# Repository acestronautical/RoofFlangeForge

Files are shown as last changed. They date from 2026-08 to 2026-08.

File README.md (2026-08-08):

# Roof Flange Forge

Design and 3D-print flange adapters that mount cleanly on a ribbed sheet-metal
roof — van roofs, shed roofs, RV panels, corrugated agricultural buildings.
Enter your roof's rib profile, pick a flange shape, and download an STL that
bridges the ribs and gives a fan, vent, skylight, or duct a flat, sealable
base.

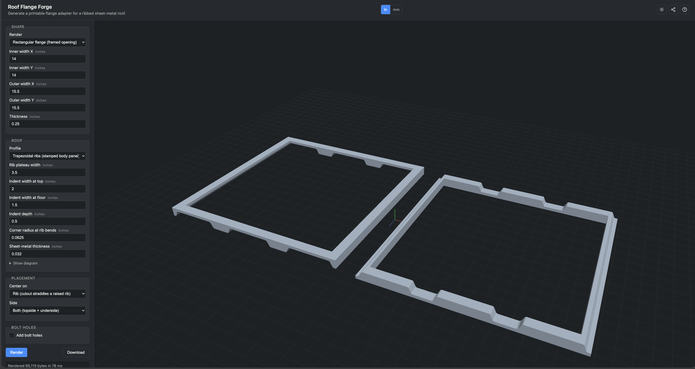
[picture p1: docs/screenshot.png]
Roof Flange Forge


## Get it

- **In your browser** — <https://acestronautical.github.io/RoofFlangeForge/>
- **As a desktop app** — [download the latest release](https://github.com/acestronautical/RoofFlangeForge/releases/latest)
  for macOS, Windows, or Linux

Both versions do the same thing and work fully offline once loaded.

## What you can make

- **Circular flange** — round mounting ring for round-flange fittings (Maxxair
  Dome, 6"–7" vents, roof jacks, small skylights)
- **Rectangular flange** — framed opening for fans in a rectangular cutout
  (defaults suit MaxxFan-family 14×14" fans)
- **Strip** — a mounting bar with no cutout, for roof-rack rails, panel mount
  bases, cable tie-downs
- **Roof preview** — an at-a-glance cross-section of the profile you configured,
  handy when you're eyeballing whether your numbers match the real panel

Every flange can be configured for either a **trapezoidal** roof (stamped body
panels, most vans) or a **corrugated** roof (sinusoidal, e.g. barn tin), and
comes in a **topside** piece, an **underside** piece, or **both at once** (both
mating parts spread apart in one STL, ready to sandwich the sheet metal
between them).

Optional bolt holes can be turned on with a single click. They auto-center on
the ring material and expose a signed offset to nudge them inward or outward.

## Using it

1. Open the app, pick **inches** or **millimeters** at the top.
2. Pick a **Shape** and set its size.
3. Set the **Roof** profile and dimensions to match the sheet metal you're
   mounting on. Every field has a hover hint; the **Show diagram** link at
   the bottom of the Roof section pops up a labeled cross-section.
4. Choose **Placement** — whether the flange center sits over a rib or an
   indent, and whether you're printing the topside, underside, or both.
5. Turn on **Bolt holes** if you want the holes pre-drilled.
6. Hit **Render**, review the preview, then **Download**.

The share button in the top-right copies a link that reproduces your exact
STL — bookmark it, send it to a friend, or come back to it later.

Read the [help modal](https://acestronautical.github.io/RoofFlangeForge/?help=1)
in the app for tips on tolerance adjustments (loose fit, snug fit, sheet
thickness, corner radius) before you commit to a full print.

## Credits

Development notes for the code are in [DEV.md](DEV.md).

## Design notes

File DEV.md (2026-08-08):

# Developer notes

Public docs live in [README.md](README.md). This file is for people working
on the code.

## Layout

```
cli/scad/                  Parametric SCAD sources (single source of truth)
cli/build_stls.sh          Batch-render every variant into generated_stl/
cli/tests/reproducibility.sh   Two-render byte-diff test (7 configs)
web/                       Vite + TypeScript + three.js web app
web/electron/main.cjs      Electron main process (npm run electron:dist)
web/public/openscad/       Vendored openscad-wasm (Manifold, ~11 MB)
web/public/scad -> ../../cli/scad   symlink; single source of truth for SCAD
.github/workflows/
  pages.yml                Push to main -> deploy web app to GitHub Pages
  test.yml                 Push / PR -> reproducibility test (nightly OpenSCAD)
  release.yml              Tag push (v*) -> build .dmg/.exe/.AppImage matrix
  build-openscad-wasm.yml  Manual dispatch -> rebuild openscad-wasm, open PR
```

## Local dev

```bash
cd web
npm install
npm run dev        # http://localhost:5173
npm run typecheck
npm run electron:dev   # runs Electron pointed at the Vite server
npm run electron:dist  # packages a signed installer for your host OS
```

## CLI

Install a modern OpenSCAD locally (`brew install openscad`), then one-off:

```bash
openscad \
    -D 'ID=6.375' \
    -D 'OD=10.5' \
    -D 'side="top"' \
    -D 'bolt_holes=true' \
    -o adapter.stl \
    cli/scad/circular_adapter.scad
```

Every top-level variable in the SCAD is overridable via `-D`.

`cli/build_stls.sh` batch-renders the standard variants.

## Reproducibility test

`cli/tests/reproducibility.sh` renders a 7-config matrix twice with the same
OpenSCAD binary and asserts byte-identical output. Catches accidental
non-determinism (unset variables, iteration-order sensitivity, floating-point
edge cases) that would break shareable-URL reproducibility.

Run locally: `bash cli/tests/reproducibility.sh`. On CI the workflow installs
the nightly OpenSCAD AppImage — Ubuntu's apt is too old for Manifold (which
is deterministic; CGAL isn't for our bolt-hole configs).

## Cutting a release

```bash
git tag v0.2.0
git push --tags
```

The **Release desktop builds** workflow packages the Electron app on
macos-latest / windows-latest / ubuntu-latest in parallel and attaches the
installers to the GitHub Release for that tag via `softprops/action-gh-release`.

If you need to redo a release: `git push origin :v0.2.0 && git tag -d v0.2.0 &&
git tag v0.2.0 && git push --tags` (force re-tag, retriggers the workflow).

## Upgrading openscad-wasm

Actions tab → **Build openscad-wasm from main** → *Run workflow*. Docker-builds
openscad-wasm from source, filters out the fonts+MCAD files we don't use,
copies the fresh artifacts into `web/public/openscad/`, and opens a PR to
review. Merge to ship.

If the workflow fails at "Open PR" with
*"GitHub Actions is not permitted to create or approve pull requests"*, either
open the PR manually from the pushed branch `chore/openscad-wasm-upgrade`, or
enable the setting at *Repo Settings → Actions → General → Workflow permissions*.

## Design notes

- The roof profile is periodic: **trapezoidal** is defined by `rib_width`,
  `indent_top_w`, `indent_bot_w`, `indent_depth`, `corner_r`; **corrugated**
  by `corr_pitch` and `corr_depth`.
- Chamfered rib bends are baked into the surface polygon (no offset/minkowski
  gymnastics), so the geometry stays manifold at any `corner_r`. See
  `chamfer_polyline` in `trapezoidal_roof.scad`.
- Every adapter is `blank − roof_cutter − bolt_pattern` (bolts opt-in).
  Topside and underside are the two halves of one prism split along the
  roof surface, with a `sheet_thickness` gap between them. Their union fills
  a constant-thickness volume.
- `roof_cutter()` dispatches on `roof_profile` at render time, so switching
  between trapezoidal and corrugated is one variable, not a different file.
- Top-level `render_all()` handles `side="both"` by translating a topside
  and an underside apart and rendering both — makes a print-ready STL with
  both mating parts on the bed in one job.
- `bolt_pattern.scad` is fully isolated: adapters `include` it and gate its
  effect on a `bolt_holes = false` default. Set the flag off and the STL is
  byte-identical to a build without the file.

## Deploying

The `Deploy to GitHub Pages` workflow triggers on every push to `main`. It
builds the web app with `base: "/RoofFlangeForge/"` and publishes
`web/dist/` to Pages. The Electron build uses the same source with a relative
base URL (`ELECTRON=1 vite build`).

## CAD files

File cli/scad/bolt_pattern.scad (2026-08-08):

// =============================================================================
// bolt_pattern.scad
//
// Bolt-hole cutter modules. Each generates a set of vertical through-hole
// cylinders you subtract from an adapter body. Fully self-contained: no
// dependency on adapter geometry beyond the enable flag and pass-through
// dimensions.
//
// Every adapter honors a top-level `bolt_holes = false` variable; when set
// true, the adapter subtracts the matching bolt pattern in a difference()
// pass. Leave the flag off (the default) and this file has zero effect --
// the geometry is byte-identical to the pre-bolt-holes version.
// =============================================================================

bolt_eps = 0.010;                        // face-clearing overlap on each end

// Centered vertically around z=0; caller sizes h to span the adapter.
module bolt_cyl(d, h) {
    translate([0, 0, -h/2])
        cylinder(h = h, d = d, $fn = 32);
}

// n bolts evenly spaced on a bolt circle of diameter pcd.
module circular_bolt_pattern(n, pcd, hole_d, h, angle_offset = 0) {
    for (i = [0 : n-1]) {
        a = angle_offset + i * 360 / n;
        translate([pcd/2 * cos(a), pcd/2 * sin(a), 0])
            bolt_cyl(hole_d, h);
    }
}

// Bolts around the perimeter of a rectangle: corners are always included,
// with n_per_side controlling total bolts on each edge (corners shared
// between the two edges they touch, so n_per_side = 2 gives 4 total,
// n_per_side = 3 gives 8, n_per_side = 4 gives 12, etc.).
module rectangular_bolt_pattern(outer_x, outer_y, n_per_side, edge_inset, hole_d, h) {
    ex = outer_x / 2 - edge_inset;
    ey = outer_y / 2 - edge_inset;

    for (p = [[+ex, +ey], [-ex, +ey], [+ex, -ey], [-ex, -ey]])
        translate([p[0], p[1], 0]) bolt_cyl(hole_d, h);

    if (n_per_side >= 3) {
        for (i = [1 : n_per_side - 2]) {
            x = -ex + i * (2 * ex) / (n_per_side - 1);
            y = -ey + i * (2 * ey) / (n_per_side - 1);
            translate([x, +ey, 0]) bolt_cyl(hole_d, h);
            translate([x, -ey, 0]) bolt_cyl(hole_d, h);
            translate([+ex, y, 0]) bolt_cyl(hole_d, h);
            translate([-ex, y, 0]) bolt_cyl(hole_d, h);
        }
    }
}

// n evenly-spaced bolts on the centerline of a strip of length strip_x.
module strip_bolt_pattern(strip_x, n, edge_inset, hole_d, h) {
    xs = n == 1 ? [0]
        : [ for (i = [0 : n-1]) -strip_x/2 + edge_inset + i * (strip_x - 2*edge_inset) / (n - 1) ];
    for (x = xs)
        translate([x, 0, 0]) bolt_cyl(hole_d, h);
}

// Drop a bolt at each X in xs, on the strip centerline (y=0).
module bolt_column_at(xs, hole_d, h) {
    for (x = xs)
        translate([x, 0, 0]) bolt_cyl(hole_d, h);
}

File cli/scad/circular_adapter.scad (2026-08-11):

// =============================================================================
// circular_adapter.scad
//
// An annular mounting adapter that conforms to a periodic trapezoidal-rib
// roof (see trapezoidal_roof.scad).
//
// The topside and underside variants are the two halves of a single cylinder
// split along the roof surface:
//
//   side = "top"    -> the piece ABOVE the roof, with pads that drop DOWN
//                      into the indents
//   side = "bottom" -> the piece BELOW the roof, with pockets that receive
//                      those pads from below
//
// Their union fills a solid ring cylinder of thickness `main_thick + indent_depth`
// on each side of the roof plateau plane (2 * main_thick when main_thick equals
// indent_depth, which is the default).
//
// All dimensions in inches; final scale converts to millimeters.
// =============================================================================

include <trapezoidal_roof.scad>
include <corrugated_roof.scad>
include <bolt_pattern.scad>

// -----------------------------------------------------------------------------
// Roof profile: which cross-section to conform the underside to
// -----------------------------------------------------------------------------
roof_profile = "trapezoidal";            // "trapezoidal" or "corrugated"
roof_depth   = (roof_profile == "corrugated") ? corr_depth : indent_depth;

// -----------------------------------------------------------------------------
// Adapter shape
// -----------------------------------------------------------------------------
ID          = 6.500;                      // inner diameter (must be >= the opening you're framing)
OD          = 10.000;                     // outer diameter
main_thick  = roof_depth;                 // thickness of this piece above (topside) or below (underside) the rib plateau plane

// -----------------------------------------------------------------------------
// Position of the flange center on the roof and which side the adapter mounts on
// -----------------------------------------------------------------------------
flange_offset_x = 0;                         // 0 = rib-centered; indent_center_x = indent-centered
side         = "top";                     // "top" (outside), "bottom" (inside), or "both" (both sides side by side)

// -----------------------------------------------------------------------------
// Fit tolerance: uniform clearance normal to the roof surface. Grows the
// cutter (via offset() before extrusion) so the printed pads sit in the
// real indents with slop instead of an exact-fit wedge. The plateau contact
// line is preserved via an intersection clip -- see trapezoidal_roof.scad.
// -----------------------------------------------------------------------------
tolerance   = 0;                          // per-side clearance around the roof-mating features

// -----------------------------------------------------------------------------
// Bolt holes (opt-in). See bolt_pattern.scad.
// -----------------------------------------------------------------------------
bolt_holes  = false;                      // set true to subtract a bolt pattern
bolt_n      = 8;                          // number of bolts on the bolt circle
bolt_pcd    = (ID + OD) / 2;              // pitch circle diameter (default: centered on the ring)
bolt_angle  = 0;                          // rotation of the bolt pattern about the flange center, in degrees
bolt_hole_d = 0.250;                      // through-hole diameter

// -----------------------------------------------------------------------------
// Render controls
// -----------------------------------------------------------------------------
$fn    = 240;
IN2MM  = 25.4;

// -----------------------------------------------------------------------------
// Derived: cutter extents. Z range is computed per-side inside the module
// (see circular_adapter) so "both" mode can render top + bottom at once.
// -----------------------------------------------------------------------------
cut_xy = 2 * OD;
cut_z  = 4 * roof_depth;

scale([IN2MM, IN2MM, IN2MM]) render_all();

// =============================================================================
// Modules
// =============================================================================

module render_all() {
    if (side == "both") {
        gap = OD * 1.1;
        translate([-gap/2, 0, 0]) circular_adapter("top");
        translate([+gap/2, 0, 0]) circular_adapter("bottom");
    } else {
        circular_adapter(side);
    }
}

module circular_adapter(s = side) {
    z_top = (s == "top") ? +main_thick    : -sheet_thickness;
    z_bot = (s == "top") ? -roof_depth    : -main_thick - roof_depth - sheet_thickness;
    difference() {
        translate([0, 0, z_bot])
            linear_extrude(height = z_top - z_bot)
                difference() {
                    circle(d = OD);
                    circle(d = ID);
                }
        roof_cutter(s);
        if (bolt_holes)
            circular_bolt_pattern(
                n            = bolt_n,
                pcd          = bolt_pcd,
                hole_d       = bolt_hole_d,
                h            = 4 * (main_thick + roof_depth + sheet_thickness),
                angle_offset = bolt_angle
            );
    }
}

module roof_cutter(s = side) {
    if (roof_profile == "corrugated")
        corrugated_roof_cutter(
            flange_offset_x = flange_offset_x,
            pitch        = corr_pitch,
            depth        = corr_depth,
            cut_xy       = cut_xy,
            cut_z        = cut_z,
            side         = s,
            thickness    = sheet_thickness,
            tolerance    = tolerance
        );
    else
        trapezoidal_roof_cutter(
            flange_offset_x = flange_offset_x,
            cut_xy       = cut_xy,
            cut_z        = cut_z,
            side         = s,
            thickness    = sheet_thickness,
            tolerance    = tolerance
        );
}

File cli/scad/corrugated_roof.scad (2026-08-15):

// =============================================================================
// corrugated_roof.scad
//
// Parametric model of a periodic sinusoidal "corrugated" sheet-metal roof --
// the classic wavy metal panel seen on sheds, barns, and some industrial
// vehicles. Signature-compatible with trapezoidal_roof.scad's cutter so the
// adapters can dispatch between the two at render time.
//
// Exports:
//     module corrugated_roof_cutter(...)  - solid block on one side of the
//                                           roof surface, sized for
//                                           subtraction from a blank.
//     module corrugated_roof_sheet(...)   - thin sheet-metal-like
//                                           visualization of the roof.
//
// The trapezoidal file owns `sheet_thickness` (and `corner_r`); this file
// only declares corrugated-specific variables so both can be `include`d in
// the same adapter without collisions.
// =============================================================================

// -----------------------------------------------------------------------------
// Corrugated cross-section defaults (inches). Overridable via -D.
// -----------------------------------------------------------------------------
corr_pitch = 2.667;    // rib-to-rib spacing (one full wave, "wavelength")
corr_depth = 0.500;    // peak-to-trough vertical distance

// Derived
corr_indent_center_x = corr_pitch / 2;   // half-wavelength from a peak = trough centerline

// =============================================================================
// corrugated_roof_cutter(flange_offset_x, pitch, depth, cut_xy, cut_z, side,
//                       thickness, samples_per_pitch)
//
// See trapezoidal_roof_cutter for parameter semantics. `flange_offset_x = 0`
// puts a peak (rib) at X = 0; `flange_offset_x = corr_indent_center_x` puts a
// trough (indent) at X = 0.
// =============================================================================
module corrugated_roof_cutter(
    flange_offset_x      = 0,
    pitch             = corr_pitch,
    depth             = corr_depth,
    cut_xy            = 40,
    cut_z             = 5,
    side              = "top",
    thickness         = 0.032,
    samples_per_pitch = 64,
    tolerance         = 0
) {
    z_shift = (side == "bottom") ? -thickness : 0;
    // top_y is the tiny above-plateau overlap baked into the profile; used
    // here as the plateau reference line for the tolerance clip.
    top_y = 0.010;
    translate([0, 0, z_shift])
        rotate([90, 0, 0])
            linear_extrude(height = 2*cut_xy, center = true)
                if (tolerance <= 0) {
                    corrugated_roof_profile_2d(
                        flange_offset_x      = flange_offset_x,
                        pitch             = pitch,
                        depth             = depth,
                        cut_xy            = cut_xy,
                        cut_z             = cut_z,
                        side              = side,
                        samples_per_pitch = samples_per_pitch
                    );
                } else if (side == "top") {
                    intersection() {
                        offset(delta = tolerance)
                            corrugated_roof_profile_2d(
                                flange_offset_x      = flange_offset_x,
                                pitch             = pitch,
                                depth             = depth,
                                cut_xy            = cut_xy,
                                cut_z             = cut_z,
                                side              = "top",
                                samples_per_pitch = samples_per_pitch
                            );
                        translate([-2*cut_xy, -2*cut_z])
                            square([4*cut_xy, 2*cut_z + top_y]);
                    }
                } else {
                    // See trapezoidal_roof_cutter for the rationale: for the
                    // bottom side we can't just clip the offset polygon,
                    // because the trough pockets live below the plateau
                    // line and a symmetric clip would erase them. Union the
                    // above-plateau slice of the offset with an offset of
                    // just the below-plateau trough bulges instead.
                    union() {
                        intersection() {
                            offset(delta = tolerance)
                                corrugated_roof_profile_2d(
                                    flange_offset_x      = flange_offset_x,
                                    pitch             = pitch,
                                    depth             = depth,
                                    cut_xy            = cut_xy,
                                    cut_z             = cut_z,
                                    side              = "bottom",
                                    samples_per_pitch = samples_per_pitch
                                );
                            translate([-2*cut_xy, top_y])
                                square([4*cut_xy, 4*cut_z]);
                        }
                        offset(delta = tolerance) intersection() {
                            corrugated_roof_profile_2d(
                                flange_offset_x      = flange_offset_x,
                                pitch             = pitch,
                                depth             = depth,
                                cut_xy            = cut_xy,
                                cut_z             = cut_z,
                                side              = "bottom",
                                samples_per_pitch = samples_per_pitch
                            );
                            translate([-2*cut_xy, -2*cut_z])
                                square([4*cut_xy, 2*cut_z + top_y]);
                        }
                    }
                }
}

// The 2D cross-section of the cutter. `y = top_y` at the peak (rib plateau
// level, at Z = 0 after the extrude/rotate) and `y = top_y - depth` at the
// trough. Enough samples per wavelength that the polygon reads as a smooth
// curve after linear_extrude.
module corrugated_roof_profile_2d(
    flange_offset_x,
    pitch,
    depth,
    cut_xy,
    cut_z,
    side              = "top",
    samples_per_pitch = 64
) {
    top_y   = 0.010;              // small overlap above the rib plateau, matches trapezoidal
    amp     = depth / 2;          // half of peak-to-trough
    total_x = 2 * cut_xy;
    n       = max(2, ceil(total_x / pitch * samples_per_pitch));
    step    = total_x / n;

    // z(x) = top_y - amp + amp*cos(...) so peaks touch top_y and troughs sit at top_y - depth.
    surface_ltr = [
        for (i = [0 : n])
            let (x = -cut_xy + i * step)
            [x, top_y - amp + amp * cos(360 * (x - flange_offset_x) / pitch)]
    ];

    pts = (side == "top")
        ? concat(
            [[-cut_xy, -cut_z], [+cut_xy, -cut_z]],
            [ for (i = [n : -1 : 0]) surface_ltr[i] ]
        )
        : concat(
            [[+cut_xy, +cut_z], [-cut_xy, +cut_z]],
            surface_ltr
        );

    polygon(pts);
}

// =============================================================================
// corrugated_roof_sheet(...)
//
// Thin sheet-metal visualization of the roof. Same top surface as
// corrugated_roof_cutter, closed to a bottom offset down by `sheet_thickness`.
// =============================================================================
module corrugated_roof_sheet(
    flange_offset_x      = 0,
    pitch             = corr_pitch,
    depth             = corr_depth,
    cut_xy            = 12,
    sheet_thickness   = 0.100,     // visualization thickness; not physically accurate
    samples_per_pitch = 64
) {
    rotate([90, 0, 0])
        linear_extrude(height = 2*cut_xy, center = true)
            corrugated_roof_sheet_2d(
                flange_offset_x      = flange_offset_x,
                pitch             = pitch,
                depth             = depth,
                cut_xy            = cut_xy,
                sheet_thickness   = sheet_thickness,
                samples_per_pitch = samples_per_pitch
            );
}

module corrugated_roof_sheet_2d(
    flange_offset_x,
    pitch,
    depth,
    cut_xy,
    sheet_thickness,
    samples_per_pitch = 64
) {
    top_y   = 0.010;
    amp     = depth / 2;
    total_x = 2 * cut_xy;
    n       = max(2, ceil(total_x / pitch * samples_per_pitch));
    step    = total_x / n;

    top_ltr = [
        for (i = [0 : n])
            let (x = -cut_xy + i * step)
            [x, top_y - amp + amp * cos(360 * (x - flange_offset_x) / pitch)]
    ];
    // Bottom face parallels the top by shifting each Y down by sheet_thickness.
    bot_rtl = [ for (i = [n : -1 : 0]) [ top_ltr[i][0], top_ltr[i][1] - sheet_thickness ] ];
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

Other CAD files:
cli/scad/corrugated_roof_preview.scad
cli/scad/rectangular_adapter.scad
cli/scad/strip.scad
cli/scad/trapezoidal_roof.scad
cli/scad/trapezoidal_roof_preview.scad

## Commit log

2026-08-08 Initial commit
    Parametric roof-flange adapter generator with two front-ends:
    - Web app (web/): Vite + TypeScript + three.js; renders in-browser via
    openscad-wasm 2022.03.20, live 3D preview with 1-inch scale grid,
    unit-aware form (inches / mm), STL download.
    - CLI (cli/): build_stls.sh renders every prebuilt variant to
    generated_stl/ via local OpenSCAD.
    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
    [circular_adapter.scad, rectangular_adapter.scad, trapezoidal_roof.scad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]
2026-08-08 feat(web): render in a Web Worker with live progress ticker
    openscad-wasm's callMain() is synchronous and blocks the main thread, so a
    naive setInterval-based progress indicator never got a chance to fire. Move
    the openscad-wasm instance into a Web Worker (openscad.worker.ts) and drive
    it through a small message-passing client (openscad-runner.ts).
    Result:
    - Braille spinner + elapsed-time counter that actually updates during renders
    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
2026-08-08 feat: add "strip" shape (rectangular mounting bar, no cutout)
    Same rib-conforming underside as the rectangular adapter, minus the inner
    cutout -- a solid bar sized in inches (defaults 15.5 x 3). Useful for roof-
    rack rails, panel mount bases, and cable tie-downs on ribbed sheet-metal
    roofs.
    - cli/scad/strip.scad: new module (topside/underside variants share the
    same split-prism trick as the other adapters).
    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
    [adapter.scad, strip.scad]
2026-08-08 feat: add corrugated (sinusoidal) roof profile
    Roof cross-section is now selectable: trapezoidal (stamped body-panel
    ribs, default) or corrugated (sinusoidal, like barn tin / Ag-panel).
    Every adapter (circular / rectangular / strip) dispatches on the
    "roof_profile" variable at render time.
    - cli/scad/corrugated_roof.scad: new module
    corrugated_roof_cutter(fan_offset_x, pitch, depth, cut_xy, cut_z,
    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
    [circular_adapter.scad, corrugated_roof.scad, corrugated_roof_preview.scad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]
2026-08-08 fix(scad): bake chamfered rib bends into the trapezoidal profile
    Real stamped roof panels have chamfered/rounded transitions at the
    rib-to-sidewall and sidewall-to-floor bends, not sharp 90-degree
    corners. Previous versions tried to reproduce this via 2D offset
    tricks and 3D minkowski wrappers -- both fragile: the offset chain
    eroded the roof-preview sheet to disconnected strips, and minkowski
    produced non-manifold meshes.
    Replace both with the obvious fix: chamfer the profile points
    themselves. Each interior corner in trapezoidal_roof_surface_pts is
    replaced by two points offset by corner_r along the two adjacent
    edges (clamped to 45%% of each edge so a huge corner_r can't collapse
    the tra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
    [trapezoidal_roof.scad]
2026-08-08 fix(web): preserve camera pose across renders
    Every load() call was calling frameMesh() which reset camera.position
    and controls.target to defaults, snapping the view back to the corner
    after every parameter tweak. Track a hasFramed flag so only the very
    first render frames the mesh; subsequent renders leave the user's
    orbit/pan/zoom alone.
2026-08-08 feat(web): shareable URLs + header share button
    Every successful render now pushes the current parameter state into
    the URL query string via history.replaceState (no history clutter).
    A small share-icon button lives in the top-right of the header;
    clicking it writes the current URL to the clipboard.
    On page load, ?key=value pairs are applied back to the form. Units,
    shape, and roof_profile are applied first so visibility toggles
    settle before the mode-specific fields are populated. Disabled
    (hidden) fields are skipped when serializing so the URL only carries
    the parameters that actually apply.
    Clipboard failures (permissions in a preview iframe, etc.) fall back
    to window.prompt so the link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
2026-08-08 ci: patch flaky gmplib.org mirror + retry hardening
    The openscad-wasm Makefile pulls gmp-6.3.0 directly from gmplib.org,
    which routinely rate-limits or blocks CI IP ranges (last run stalled
    for 40+ minutes retrying the same download). Swap the URL for the
    GNU FTP mirror before invoking make, and beef up every wget in the
    Makefile with --tries=5 --timeout=30 --waitretry=15 so a transient
    blip on any other tarball mirror (mpfr, boost, cmake) doesn't sink
    a long-running build either.
2026-08-08 feat(web): toast confirms Copy share link, shows the URL
    The icon-only share button was ambiguous -- clicking it did the
    right thing but there was no signal to confirm. Now a top-right
    toast pops up with a green "Link copied to clipboard" header and
    the full URL underneath, so users can both verify the action
    succeeded and eyeball the URL before pasting it somewhere. Falls
    back through window.prompt if navigator.clipboard is unavailable
    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
2026-08-08 feat(web): sensible spinner steps per input, unit-aware
    Every numeric input previously used step="any", so the arrow
    buttons and keyboard up/down keys stepped by the browser default
    (usually 0.01), which felt arbitrary. Per-field steps now:
    ID, OD, inner_*, outer_*, strip_* 0.25 in / 5 mm
    rib_width, indent_*_w, corr_pitch 0.125 in / 2 mm
    indent_depth, corner_r, corr_depth, 0.0625 in / 1 mm
    main_thick
    preview_xy 1 in / 10 mm
    preview_thickness 0.01 in / 0.25 mm
    sheet_thickness 0.001 in / 0.05 mm
    Steps are swapped when the units select flips. Typed values are
    unrestricted -- the form has noval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
2026-08-08 chore: cleanup pass (kill legacy Code/, de-van-ify labels)
    - Delete Code/adapter.scad: the pre-refactor monolithic scad file,
    fully superseded by cli/scad/{circular,rectangular,strip}_adapter.
    - Shape select: "Rectangular flange (14x14-style)" was ambiguous
    (14x14 what?). Rename to "Rectangular flange (framed opening)",
    which describes what the geometry actually is; the MaxxFan 14x14"
    callout survives in the SCAD/README as the source of the defaults.
    - SCAD comments: swap "fan cutout / fan center / outside of vehicle"
    for the roof-agnostic "opening / roof center / outside of roof"
    wording; still mention MaxxFan as the origin of the numeric
    defaults where relevant.
    - .gitignore: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
    [adapter.scad, circular_adapter.scad, rectangular_adapter.scad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]
2026-08-08 rename fan_offset_x -> flange_offset_x; feat: auto-render; test: reproducibility
    1) Rename fan_offset_x -> flange_offset_x across every SCAD file,
    the CLI batch script, and web/src/main.ts. Last van-ism after the
    comment sweep. URL params dont carry this variable (mount/side
    are the wire format), so existing shared URLs keep working.
    2) feat(web): auto-render when ?render=1 is on the URL. Also stamp
    render=1 onto the URL in writeParamsToUrl, so every subsequent
    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
    [circular_adapter.scad, corrugated_roof.scad, corrugated_roof_preview.scad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]
2026-08-08 feat(web): help modal + light/dark theme toggle
    - Help button (?) in the header opens a modal explaining the
    workflow, topside vs underside, print/fitment tolerance tips
    (loose fit, snug fit, sheet thickness, corner_r), and how the
    share link works. Backdrop click or Escape closes it.
    - Theme button (sun/moon) toggles between dark and light palettes,
    persisted in localStorage. Viewer background follows so the STL
    isn't glaring against a dark UI or floating on a bright canvas.
    - Light palette uses a soft neutral gray (not pure white) so it
    reads as "paper" instead of blinding.
    - Header buttons wrapped in .header-actions so they group on the
    far right; help sits rightmost.
2026-08-08 feat: bolt-hole layout polish
    - Strip: 'Bolt count' becomes 'Bolts on' with Every rib / Every
    indent / Every rib and indent / Every other rib / Every other
    indent. Placement follows the roof pattern instead of guessing a
    spacing. Features whose center-of-rib or center-of-indent has less
    than half their width inside the strip get skipped so a partial
    edge feature doesn't turn into a bolt hole hanging off the end.
    - Circular / rectangular: drop the raw 'Bolt circle diameter' and
    'Edge inset' inputs. Bolts auto-center on the ring material and
    expose a single signed 'Offset from center' -- positive pushes
    outward, negative inward.
    - SCAD defaults for both auto-center too:
    cir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
    [bolt_pattern.scad, circular_adapter.scad, rectangular_adapter.scad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]
2026-08-08 chore: pull in newer openscad-wasm (Manifold), drop fonts/mcad bloat
    Rebuilt WASM landed on chore/openscad-wasm-upgrade with the new
    build/-layout Makefile fix from earlier. Merging into main:
    - web/public/openscad/openscad.wasm goes 7.7 MB -> 11 MB, now
    includes Manifold as the default backend. Rendering times drop
    5-10x in the browser (typical circular with bolts: ~1200 ms ->
    ~170 ms). No code change needed -- Manifold is on by default;
    the old --enable=manifold flag is now a harmless no-op that the
    build actually warns about, so drop it.
    - Delete openscad.fonts.{js,d.ts} (7.8 MB of base64-embedded fonts)
    and openscad.mcad.{js,d.ts} (480 KB of MCAD library). Both are
    OPTIONA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
2026-08-08 fix(web): checkboxes weren't restored from share-URL params
    serializeParams walked form.elements and did params.set(name, el.value)
    for every input, but for a checkbox el.value is the string "on"
    regardless of the checked state. So the URL always carried
    bolt_holes=on even when the box was off. Symmetrically, applyParams
    did el.value = value for the same input, which sets the .value
    attribute but does not touch .checked -- so loading a shared URL
    with bolt_holes=on left the checkbox unchecked and the render
    came out without any holes.
    Fix both sides:
    - serialize: skip unchecked checkboxes; write "1" for checked ones
    - apply: set .checked from the value (accept 1/on/true) and fire
    a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
2026-08-08 feat(web): move Units into the header as an in/mm segmented control
    The 'Units' fieldset was taking the whole first slot of the crowded
    left-hand form for a two-option control. Move it into the header as
    a segmented in/mm toggle sitting between the title and the icon
    buttons; header uses justify-content: space-between so the three
    groups (title / units / actions) land left-center-right naturally.
    The <select name="units"> becomes a hidden <input> inside the form
    so serialize/apply URL round-trips and the existing change-driven
    unit conversion + step-swap logic keep working unchanged. The
    segmented buttons just flip that hidden value and dispatch change.
2026-08-08 fix(web): default camera framing was too far -- multiplier 2.5 -> 1.4
    frameMesh() places the camera at (maxDim/2 / tan(fov/2)) * K away
    from the model. K=2.5 left about 60%% of the viewport empty around
    the mesh; drop to 1.4 so the model fills the view without touching
    the edges. User's camera-persistence fix means this only affects
    the first render, so tweaking after load is still uninterrupted.
2026-08-08 feat(web): shorten action buttons + push them apart
    'Render STL' / 'Download STL' -> 'Render' / 'Download' (both are
    STL, the buttons are next to a big STL preview -- redundant). Also
    switch .actions to justify-content: space-between so the two
    buttons anchor to opposite ends of the row instead of hugging.
2026-08-08 chore(web): move Bolt holes fieldset below Placement
    Bolt holes are a nice-to-have layer applied on top of the base
    geometry defined by Placement (mount + side), so they should read
    after Placement in the form flow. No behavior change.
2026-08-08 feat(web): spell out unit suffixes (in -> inches, mm -> millimeters)
    Every '(in)' / '(mm)' next to an input becomes 'inches' /
    'millimeters'. Muted styling on .unit-suffix (color: var(--muted),
    opacity 0.7, smaller weight/size) so the suffix reads as secondary
    context to the label instead of visually competing with the input
    name.
2026-08-08 ci: use OpenSCAD nightly AppImage so bolt-hole tests are deterministic
    Ubuntu apt's openscad is 2019.05, CGAL-only. That build's hash-set
    iteration order in the boolean engine leaks into the STL byte layout
    for our circular_with_bolts and rectangular_with_bolts configs --
    two identical runs produce different bytes and the reproducibility
    test fails on CI while passing locally (where openscad@snapshot
    uses Manifold).
    Switch to the latest OpenSCAD nightly AppImage from
    files.openscad.org, which ships Manifold as the default backend and
    is byte-deterministic. Extract the AppImage and symlink AppRun into
    /usr/local/bin/openscad so the existing test script picks it up.
2026-08-08 chore(web): rename 'Ring thickness' -> 'Thickness'
    'Ring' only fits the circular flange -- rectangular is a frame,
    strip is a bar. 'Thickness' works for all three shapes and matches
    the SCAD variable name (main_thick).
2026-08-08 feat(web): collapsible cross-section diagram + hover hints + SVG-visibility fix
    - Move the details/summary diagram wrapper to the bottom of the Roof
    fieldset (below Sheet-metal thickness) so the form scans as: pick
    a profile, punch in numbers, look at the diagram if you're unsure.
    - Rename summary text from 'Show cross-section' to 'Show diagram'.
    - Ship the corrugated cross-section SVG (pitch + depth callouts)
    alongside the trapezoidal one; the syncRoofProfileVisibility
    toggle swaps between them when Profile is flipped.
    - Add title-attr hover hints on every roof / shape / placement input
    and on the profile / mount / side selects. Explains rib_width,
    indent_top_w, indent_bot_w, in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
2026-08-08 feat: 'Both' side option renders topside and underside in one STL
    New 'Side' choice next to Topside / Underside. When selected, the
    adapter SCAD renders topside and underside pieces spread apart in
    X (circular / rectangular) or Y (strip -- long axis is X) so the
    resulting STL is a single print job with both mating parts on the
    bed simultaneously.
    Implementation:
    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
    [circular_adapter.scad, rectangular_adapter.scad, strip.scad]
2026-08-08 fix(web): header + in/mm toggle render properly on mobile
    At narrow viewports the header's justify-content: space-between
    plus a long description paragraph was pushing the middle unit
    toggle and the right-hand icon buttons off the layout. Fix:
    - flex-wrap: wrap on the header so items relax onto the next line
    instead of stacking on top of each other.
    - Hide 'Generate a printable flange adapter for a ribbed sheet-
    metal roof' on <=700px; the h1 is enough.
    - Shrink unit-toggle buttons (30x30) and icon buttons (30x30) at
    the mobile breakpoint, matching the reduced header padding.
    - Tighter header-actions gap so all three icon buttons stay
    visible on a 400px viewport.
2026-08-08 docs: update README
    - Cover every feature that's landed since the last update:
    corrugated profile, strip shape, bolt-hole opt-in, side=both,
    URL sharing / auto-render, Electron desktop app.
    - Ship download links: web + desktop releases + CLI.
    - Trim the fluff and old links, keep the design notes section
    because it's the answer to 'why is the code structured that way'.
2026-08-08 ci: install Qt/GL runtime deps for openscad + set repository in package.json
    Tests:
    - openscad-nightly links against libEGL / libGL / xcb / xkbcommon at
    runtime even in headless CLI mode. Ubuntu-latest doesn't ship
    those in the base image, so 'openscad --version' died with
    'libEGL.so.1: cannot open shared object file'. apt-install the
    minimal set (libegl1, libgl1, libglx-mesa0, libopengl0, five xcb
    libs, libxkbcommon-x11-0, libdbus-1-3, libnss3) alongside fuse.
    Release:
    - electron-builder tries to auto-detect a repository URL for its
    auto-updater config and errors out if it can't find one. Add the
    standard 'repository' field to package.json and explicitly set
    'publish: null'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
2026-08-08 docs: split public README from developer notes; refresh screenshot
    - README.md is now purely user-facing: what the tool is, where to
    get it, what it makes, and how to use it. No workflow / SCAD /
    release plumbing.
    - New DEV.md gathers directory layout, CLI internals, reproducibility
    test, release/upgrade instructions, and design notes. README ends
    with a link there for anyone who wants to hack on it.
    - docs/screenshot.png replaced with a real capture of the current UI
    (rectangular flange, side=both, trapezoidal roof, three-fieldset
    sidebar visible). Exercises features that didn't exist when the
    old screenshot was taken.
2026-08-08 docs: remove identifying references from README and SCAD comments
    [trapezoidal_roof.scad]
2026-08-11 feat: fit tolerance + bolt-hole positioning UX overhaul
    SCAD:
    - Add `tolerance` param to trapezoidal/corrugated roof cutters using
    offset() + intersection clip to shrink the roof-mating pads for real
    print fit while preserving the plateau contact plane. Opening
    dimensions (ID/OD, inner/outer, strip size) stay exact.
    - Thread tolerance through circular/rectangular/strip adapters as an
    overridable top-level variable (default 0, so existing renders are
    byte-identical -- reproducibility tests still pass).
    - Add `bolt_angle` to circular_adapter, wired to circular_bolt_pattern's
    angle_offset for rotating the bolt circle.
    Web UI:
    - New Tolerance section with a single Tolerance input.
    -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
    [circular_adapter.scad, corrugated_roof.scad, rectangular_adapter.scad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]
2026-08-11 fix: step-mismatch was flagging typed values as :invalid
    applyStepsForUnit was setting step to fractional values (0.125, 0.0625, etc.)
    from STEP_IN/STEP_MM, which made HTML5 constraint validation reject any
    typed value that wasn't an exact multiple of that step. E.g. rib_width
    3.425 with step 0.125 -> :invalid -> red border, even though the value
    is a legitimate measurement.
    Fix: force step="any" on all number inputs (except the integer counters
    bolt_n_circ and bolt_per_side which keep step="1"), and handle
    Arrow-key stepping manually via a keydown listener that consults the
    STEP_IN / STEP_MM tables. Users keep the useful per-field arrow
    increments; browser validation only checks min/max as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
2026-08-15 fix: underside cutter was flattened by tolerance clip
    The tolerance handling in trapezoidal/corrugated_roof_cutter used the
    same symmetric plateau clip for both top and bottom sides:
    intersection(offset_polygon, y >= top_y) (for side="bottom")
    That was correct for preserving the plateau contact face, but it also
    wiped out the entire indent-pocket geometry: the underside cutter's
    pockets live BELOW the plateau line at indent-x positions, and the
    symmetric intersection erased them. Result: underside came out as a
    plain ring cylinder whenever tolerance > 0.
    Fix: for side="bottom", decompose the cutter into two regions and
    union them:
    (1) offset polygon clipped to y >= top_y -- preser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
    [corrugated_roof.scad, trapezoidal_roof.scad]
2026-08-15 feat: auto-render form changes with 500ms debounce
    Any input or change event on the form starts a debounce timer. When it
    fires, form.requestSubmit() dispatches a render through the existing
    submit path. Consecutive edits within the debounce window restart the
    timer, so rapid typing / arrow-key stepping don't spam renders.
    Concurrency:
    - If a render is in flight when the timer expires, mark pendingRerender
    and re-fire once the current render finishes (trailing-edge behavior).
    Validation:
    - Auto-triggered renders silently skip when the bolt-position input is
    out of range -- users mid-typing don't get spam toasts. The input
    still shows its inline red border and 'Must be <= X' text.
    - M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
